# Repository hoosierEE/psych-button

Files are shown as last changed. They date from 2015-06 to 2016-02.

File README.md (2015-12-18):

Psych-Button
============
USB response boxes with real-time accuracy.

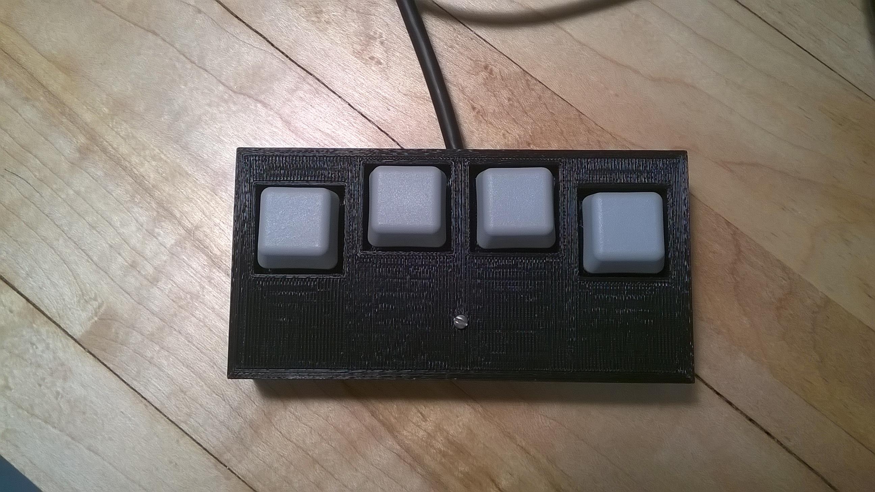
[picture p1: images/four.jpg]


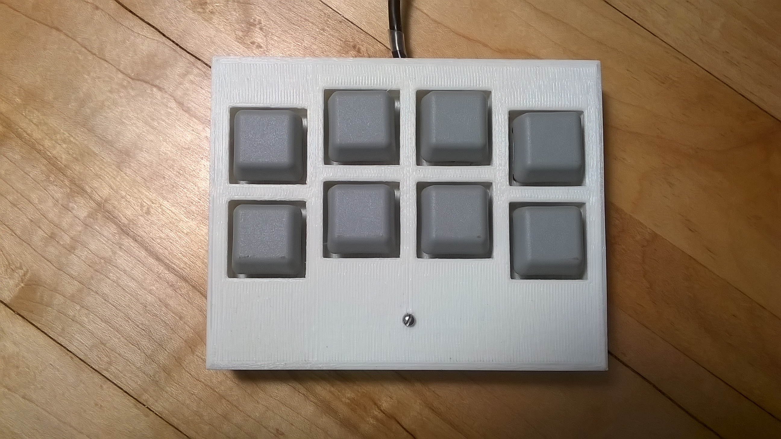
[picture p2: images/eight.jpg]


Often in psychological experiments, researchers wish to record button presses with accurate timing.  Operating system timing resolution may be inadequate, so out-of-band timing channels are required.

This project centers around a USB keyboard-like device that allows a user to measure its latency.

# Keyboard Quick Start
To use as a USB keyboard, plug-and-play.  The default keys are:

* Four-button version (left-to-right)

  * Top row: <kbd>w</kbd> <kbd>x</kbd> <kbd>y</kbd> <kbd>z</kbd>
  * Metal: <kbd>_</kbd>

* Eight-button version (left-to-right)

  * Top row: <kbd>a</kbd> <kbd>b</kbd> <kbd>c</kbd> <kbd>d</kbd>
  * Middle row: <kbd>e</kbd> <kbd>f</kbd> <kbd>g</kbd> <kbd>h</kbd>
  * Metal: <kbd>_</kbd>

> Note: if the home key (the metal pin near the center-bottom of the response box) is held, subsequent key presses will be shifted, e.g. 'a' will become 'A'.

### Timing Measurements
Round-trip delay `d` is calculated as per the [SNTP protocol, section 5](https://tools.ietf.org/html/rfc4330#section-5):

    Timestamp Name          ID   When Generated
    ------------------------------------------------------------
    Originate Timestamp     T1   time request sent by client
    Receive Timestamp       T2   time request received by server
    Transmit Timestamp      T3   time reply sent by server
    Destination Timestamp   T4   time reply received by client

    The roundtrip delay d and system clock offset t are defined as:

    d = (T4 - T1) - (T3 - T2)     t = ((T2 - T1) + (T3 - T4)) / 2.

Timing measurement from `psych-button` uses a modified version of SNTP, where `psych-button` responds to a timing request with a single number that corresponds to T3-T2.  In this scheme, T2 is always 0.  T3 is measured in integer microseconds.  Offset is not used, because `psych-button` doesn't keep a wall clock time.  The only figure we're interested in is the round-trip delay.

This procedure is done at least once, usually before an experiment, but can be done at any point in time except during data collection.

    PC (note system time T1), send character: 'T'
    psych-button: T3
    PC (note time of reply T4, calculate d given T3, T2=0)

### Python pyserial example

    cd examples/
    python pythonExample.py

The results from this test is a list of 100 numbers, corresponding to timing measurements before (t1) sending a `T` and after (t2).  The plot below (generated by [this script](images/stats.ijs), written in [J](http://www.jsoftware.com/)) shows the results of one such test, highlighting the standard deviation (blue), variance (red), arithmetic mean (green) and differences (t2<sub>i</sub> - t1<sub>i</sub>, violet):

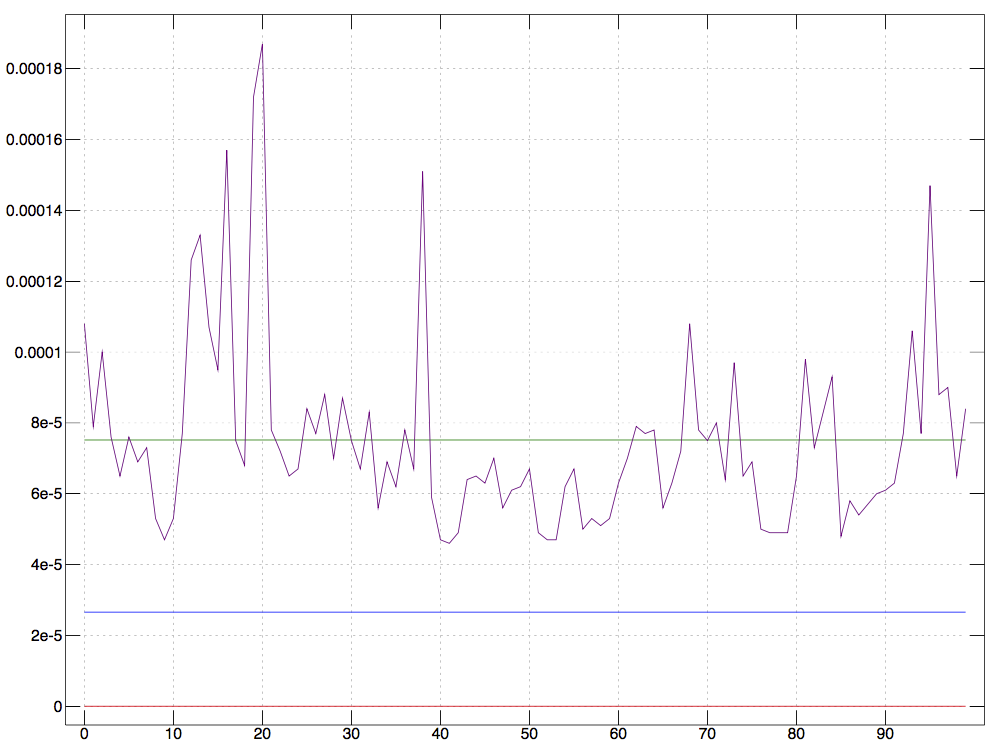
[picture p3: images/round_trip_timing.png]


Usage (Keyboard)
----------------
The Keyboard interface sends a `keydown` event when a button is pressed, or a `keyup` event when it is released.

The Keyboard interface is plug and play.  By default, the 4 (or 8) buttons correspond to <kbd>w</kbd>, <kbd>x</kbd>, <kbd>y</kbd>, and <kbd>z</kbd> keyboard events.  The "home" button prints a `_` (underbar).  Open a text editor and use the response box to "type" letters.

| button | key |
|---|:---:|
| 0 | <kbd>w</kbd> |
| 1 | <kbd>x</kbd> |
| 2 | <kbd>y</kbd> |
| 3 | <kbd>z</kbd> |

> Note: the 8-button box has the default alphabet `abcdefgh`

Usage (Serial)
--------------
Serial mode allows for monitoring the keys pressed, just like Keyboard mode, but in addition provides the following commands:

| Command | Function |
|---|---|
| `l` | list alphabet |
| `L` | modify alphabet |
| `T` | query latency |

> Note: These commands are processed immediately and may interrupt data taking, so only use them when not waiting for data.

When any button changes, the Serial interface responds by printing the state of all the buttons on a single line.

To use the serial interface, open a serial terminal on your computer using a program such as [pyserial](https://github.com/pyserial/pyserial).  Use the following settings:

* 9600 baud
* 8 data bits
* no parity
* 1 stop bit

Pressing and holding the `b0` button (and no others) will result in one line of output:

    1 0 0 0 0

Meanwhile, if you press the `b3` button, while continuing to hold `b0`, the next output will be:

    1 0 0 1 0

Finally, releasing the `b3` button, and then releasing the `b0` button, will produce this output:

    0 0 0 1 0
    0 0 0 0 0

The eight-button box is similar (here showing `b1` pressed, then released):

    0 1 0 0 0 0 0 0 0
    0 0 0 0 0 0 0 0 0

> Note: the "home" button is the last value in the line.

Notes
-----
Source code built with [platformio](http://platformio.org/#!/), a cross-platform command-line based build tool and dependency manager.

Related Reading
---------------
* [example Python serial application](http://eli.thegreenplace.net/2009/08/07/a-live-data-monitor-with-python-pyqt-and-pyserial/)
* [Synchronization Explained](http://www.ni.com/white-paper/11369/en/)
* [NTP](https://en.wikipedia.org/wiki/Network_Time_Protocol#Clock_synchronization_algorithm)
* [PTP](https://en.wikipedia.org/wiki/Precision_Time_Protocol)

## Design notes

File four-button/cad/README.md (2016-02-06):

The "source code" in this folder are CAD files ending in `.skp` which is readable by [Sketchup](http://www.sketchup.com/).

Other files include `.mtl` which are files used by Sketchup to render the "materials" of the part correctly, and `.obj` files which are used by MakerBot desktop software to 3D-print the objects.

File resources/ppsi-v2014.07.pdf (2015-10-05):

# PPSi Manual

July 2014 (ppsi-v2014.07)
Documentation about “PTP Ported to Silicon”

## Alessandro Rubini and Aurelio Colosimo for CERN (be-co-ht)

i

## Table of Contents

Chapter 2: Status, Features, Bugs | 1

## Introduction

PPSi (ptp Ported to Silicon) is an application which, in its basic operation, implements ieee 1588 specification in a way that is portable to several architectures, including OS-less ones. This manual is mainly aimed at developers: people who are working with ptp and/or White Rabbit and need to use the protocol in their own hardware or software environments. Users who simply run PPSi on the host may want to read Chapter 10 [Command Line], page 13 and little else.

## 1 Project Overview

This project originates in the context of White Rabbit, which is shortened to WR in this manual. WR is a multi-lab research project that aims at synchronizing thousands of I/O devices distributed in a network several kilometers wide; its software protocol is an extension of ptp. A WR network is made up of two devices: the WR Switch and the WR Node. White Rabbit is developed at ohwr.org: http://www.ohwr.org/projects/white-rabbit.

The WR switch is an 18-ports Gigabit Ethernet switch that runs wr-ptp as a Linux process, synchronizing each Ethernet link as either a ptp master or a ptp slave (it is a boundary clock). The WR node is an I/O device that includes a soft core that runs wr-ptp in freestanding mode (i.e., without an operating system).

PPSi, as a software package, is designed to be the ptp implementation used in WR, running both standard ptp and wr-ptp, in all possible use cases.

The algorithm and computation routines regarding the basic ieee 1588 are derived from the PTPd project, v.2.1.0 (see AUTHORS for details about copyright); but as of March 2013 very little remains of the original code base. In addition to the basic feature set we inherited from PTPd, we support raw Ethernet frames (ETH_P_1588), according to Annex F of the specification and support for protocol extensions.
We thank Danilo Sabato for fixing the bare architectures (see Section 2.2 [Architectures], page 2).

The home page of the PPSi project and the source repository are:

http://www.ohwr.org/projects/ppsigit://ohwr.org/white-rabbit/ppsi.git

## 2 Status, Features, Bugs

This document tries to summarize the status of the project, but we are working a lot on the package, so information here may be slightly out of date with respect to code.

The software package is designed to be modular: each of architectures, protocols and timing engine can be replaced by providing a proper subdirectory.

## 2.1 Build-time Configuration

After release 2013.11 we added to PPSi the Kconfig configuration engine. Configuration is now performed by running “make menuconfig” or equivalent command.

A number of ready-to use configuration files are distributed in the configs/ directory: to use any of them name it as target of make (for example: “make wrs_defconfig”).

The default configuration is unix defconfig, that builds a Unix daemon running the standard ptp version 2 protocol.

Chapter 2: Status, Features, Bugs | 2

## 2.2 Architectures

When building PPSi, the user can specify which architecture to build for, by selecting it in make menuconfig or equivalent configuration command. When cross-compiling, you need to tell your cross-compiler prefix in the configuration step, or override it at build time by passing CROSS_COMPILE= on the commabnd line.

The package currently supports the following architectures:

unix

This is the default architecture and is the normal hosted environment. The architecture is usually tested over the Linux kernel using the standard GNU libraries. Most of the code relies on standard posix conventions, so this architecture most likely works on bsd and other variants as well. We may change naming accordingly, after identifying the weak (i.e. unportable) points. This architecture supports the standard protocol on both udp and raw Ethernet, also both at the same time thanks to the per-link split of I/O methods. The architecture relies on time-unix, but it supports building with different time engines.

wrs

The White Rabbit switch build of PPSi is designed to be a separate architecture, even if the switch itself is a Linux system running on an ARM processor. The switch is a complex system, with several daemons cooperating through an IPC mechanism: the standard main loop for a standalone Unix daemon doesn’t apply to the WR switch, and modelling it as a separate architecture is the simplest and cleanest approach, in our opinion (even if it leads to some code duplication). The architectures relies on time-wrs.

wrpc

The White Rabbit PTP Core architecture is a port of PPSi to run on our I/O devices. The wrpc is a “core”, i.e. a logic block, that runs in WR-capable I/O cards. Most such cards are developed as open hardware on ohwr.org; examples are the spec (a PCIe carrier for FMC devices) and the svec (a VME carrier, with two FMC slots driver by the same WR core). The wrpc includes a soft-core cpu that runs the wr-ptp daemon. PPSi is designed to be able to be linked from wrpc-sw as its own wr-ptp engine. PPSi in this environment currently supports only raw Ethernet, not udp. The architecture uses time-wrpc.

sim

This is a simulator. It uses special time and network operations to simulate a master and a slave exchanging ptp frames. Arch-specific configuration options are implemented in arch-sim/sim-conf.c. Use of the simulator is briefly descibed in Section 3.2 [Configuring the Simulator], page 6.

bare-i386

This architecture uses system calls towards the Linux kernel but does not rely on standard libraries. The port only supports raw Ethernet frames and is thought to be a validation for our freestanding ports. The process built as bare-i386 runs on conventional x86 Linux hosts and demonstrates that PPSi works properly with no added dependencies on external libraries; freedom from dependencies is mandatory to retain the ability to build and run in freestanding environments like wrpc or microcontrollers.

Chapter 2: Status, Features, Bugs | 3

bare-x86-64
Like bare-i386, this architectures makes direct system calls without relying on external libraries. The host in this case is the a 64-bit PC instead of a 32-bit one. Both bare ports use time-bare for their timing operations.

We plan, over time, to support microcontrollers (a beta version for ARM7 is working, and we are considering Cortex-M) and bare-arm (to be tested on the WR switch).

## 2.3 Protocols

At build time, the user can select the standard protocol (selected by default by most architectures) or an extension. The code base only includes one extension, White Rabbit, which is the default choice when building for one of the WR architectures. Nothing in PPSi prevents our fellow developers to support their own ptp extension using PPSi.

Each extension lives in a subdirectory called proto-ext-name. Source files in that directory may override the implementation for the standard protocol (which lives in proto-standard) to provide their own functionalities. To simplify writing extensions, the proto-standard functions already provide hooks so the extension itself can provide callbacks while still using the basic ptp engine. The set of callbacks is currently based on the needs of WR, but we are willing to accept patches to provide more hooks as needed.
If you plan to write your own protocol extension within PPSi, please refer to how proto-extwhiterabbit is implemented.

## 2.4 Time Functions and Network Operations

PPSi supports custom implementations of time functions, so you can easily port the daemon to your own timing primitives.
The subdirectories named time-sth are used to implement timing functions; timing includes the methods that are part of two data structures: pp time operations and pp network operations. The former structure deals with getting and setting system time, while the latter deals with frame tx and rx. Network operations are concerned with timestamping the actual I/O, and that’s why they are considered part of the “timing” of PPSi.

Each architecture defines its own TIME= choice in the specific Makefile. The user can override the default by either setting the variable on the command line of PPSi, or by setting an environment variable if the architecture supports it. For example, the bare architectures force TIME=bare, while the unix architecture suggests Unix timing code (TIME?=unix). The choice for TIME= is not currently selected using Kconfig, because nobody is expected to diverge from the default choice for the architecture being built.

If you want to support a different timing engine within the Unix build system, you can use “make TIME=xyz” to request building the time-xyz subdirectory. Please note that the Unix time structures are built anyways for CONFIG_ARCH=unix, so you can piggy-back on those functions, either within your own methods or by replacing the ppi->t_ops and ppi->n_ops for the communications links that do not include your own hardware support.

## 2.5 Features

This is a summary of current and planned features for the PPSi package. As said, we are working on it these months, so the following list me be not up to date with software developments by the time you read it.
The following list if features doesn’t consider known bugs, which are listed in the following sections. Please consider such bugs transient mishaps, as we are working on them right now; anyways, it would be unfair to hide them.

Chapter 2: Status, Features, Bugs | 4

Support standard ptp and extensions. Each protocol extension should fall back to standard ptp when it detects that its peers are not able to speak the extended protocol. We don’t plan to support more than one extensions in a single build: it would be just an academic exercise until somebody contributes a new protocol extension to PPSi.

Support both hosted and freestanding environments. This is already supported, though we still lack a microcontroller implementation, and our only freestanding environment is wrpc, running on an LM32 processor.

Support multi-link operation.
The daemon manages several links at the same time, being master slave or autodetect independently on each link. The best master clock algorithm is run globally, but communication and timeouts are managed per-link.

Support both udp and raw Ethernet. We already do that. We plan use the multi-link operation to support both udp and raw Ethernet on the same network interface. Also, we expect to support udp in the WR switch, to allow progressive and seamless migration to WR if you already support ptp in your network with a udp-only implementation.

Support fall-back master links. This is needed for WR, and is being worked on. We need to track more than one master in order to switch over from one to the other within a few milliseconds and with no time glitches.

Support hardware timestamping where available. This is not yet implemented for the generic protocol, but we plan to add at least time-linux-tstamp soon.

Support bsd specifics.
Unfortunately the hosted part of the packages is slightly too much Linux-dependent. We plan to support the bsd variants as well, hoping to get interest and patches from some bsd developer.

Allow architectures to state their capabilities. Currently the command-line arguments are a an all-or-nothing thing. But, for example, bare architectures don’t support udp and other architectures may not support raw Ethernet. We plan to allow architectures to state their capabilities to report proper errors when the user tries to set up unimplemented configurations.

Support run-time enable/disable of diagnostics. We want to allow run-time modification of diagnostics flags with a per-link granularity. Currently we have configuration-based per-link diagnostic flags and global flags that can be changed at run time (for example, arch-wrpc offers that through a shell command). We think this feature is useful when you run more than a pair of interfaces and have problems on some of the links but not all of them.

## 2.6 Bugs

As of 2013-05 the project suffers from these known bugs:
- All frames must be sent according to a pseudo-random distribution; this is mostly in place but mut be audited project-wide.
- We removed peer-delay support. We plan to add it back, and actually move White Rabbit to use peer-delay ptp instead of end-to-end ptp.
- The servo for standard-ptp must be audited. We are doing it now using arch-sim support,
- udp over IPV6 is not yet supported.

Chapter 3: Configuration | 5

## 3 Configuration

PPSi support configuration files and individual configuration items passed on the command line. Such support is currently not available for freestanding architectures (the bare ones and wrpc-sw).
When PPSi starts it parses its own configuration. The command line can include a number of -f <file> and -C <item> options; they are processed in order, so later ones override earlier ones. A configuration “item” can include several directives, using the semicolon as a separator. If no configuration file is specified, the program reads the default one, which is architecture-specific (thus, the default configuration file is processed after all the command line configuration items. The default file name is /etc/ppsi.conf, but arch-wrs tries to load /wr/etc/ppsi.conf first. The source tree of PPSi includes two example configuration files in its own etc/ subdirectory.
Configuration is made of of global options and port-specific options. To configure a port, use port <name> followed by its options. The parser allocates a new ptp state machine for each new port, but allows changing configuration of an existing port. For instance, to enable frame diagnostics for a specific port, you can use:

./ppsi -f /etc/ppsi.conf -C "port eth1; diagnostics 02"
Each configuration item is made up of a keyword and an optional argument. The argument can be either a number or a string. The parser looks up keywords in three tables: a global table, an architecture-specific table and an extension-specific table. Currently, only arch-sim has specific configuration items.
The list of global configuration items is on show in lib/conf.c, as the pp_global_arglines array. Future versions of this manual may document the keywords, if the time allows it. Note: most current command-line options are going to be turned into configuration options. This applies to the priorities, intervals and thresholds, as well as the slave-only flag.

## 3.1 Configuring Faults

Configuration, for arch-unix and arch-wrs, allows to provide some fault injection.
In particular, the program allows dropping frames, in both the TX and RX paths. The configuration values state how many frames are dropped every 1000. Dropping is randomized, but the user can set the seed to ensure a repeatable dropping sequence.
Dropping transmitted frames is performed by reporting success (and the timestamp), while no frame is actually sent. A diagnostic message is generated at frames level 1, but other than than that nothing happens. Actually, arch-wrs needs to actually send a frame in order to get a timestamp back; in this case the program modifies the frame, to use a wrong Ethernet type or a wrong UDP port.
Dropping received frames is performed by actually receiving (and timestamping), but returning a special error code to the caller. Again, PPSi creates a diagnostic message at frames level 1. The following configuration lines are supported:

rx-drop <value>
tx-drop <value>
Drop value frames every 1000 frames received or sent. The randomized sequence is global.

The randomization see can be passed by pre-setting the environment variable PPSI_DROP_SEED to a decimal numeric value. For example:

export PPSI_DROP_SEED=33
before starting the daemon.

Chapter 5: Diagnostics | 6

## 3.2 Configuring the Simulator

To run the PPSi simulator you need to rely on diagnostics and specific configuration items. The configuration items are defined in arch-sim/sim-conf.c and are not individually documented here at this point.
After building with “make sim_defconfig”, you can look at how PPSi behaves in different situation. For example, to see how the servo works with default parameters you can activate servo messages at level 2, and only look at the offset from master:
./ppsi -d 0002 | grep ’Offset from master’
The diagnostic values are specified in the range 0 to 2 and represent, in this order: state machine, time, frames, servo, bmc, extensions. See Section 5.1 [Diagnostic Macros], page 6 for details. The simulator runs by default for one hour of simulated time (in a fraction of a second of running time), and the initial offset from master to slave is 0.9 seconds.

To pass configuration options, you can use the -C command line option. so, for example, to start with 0.1 seconds of offset and 1000 ns of transmission jitter, you can run like this:

./ppsi -d 0002 -C "sim_init_master_time .1; sim_jit_ns 1000"

## 4 PTP Clock Class

The clock class value (clockClass), a field of the “clock quality” structure, can be specified in the configuration file for the architectures that support such a file.
For the White Rabbit node (arch-wrpc) the class is defined according to build-time constants, set forth in constants.h.
When the node is configured as grandmaster (WRPC shell command mode gm), the class is set to 6 (a clock synchronized to a primary reference time source). However, if the internal PLL can not lock in a 60 seconds timeout, the class is set to 52: a clock that will never be a slave, but is not currently connected to a primary time source.
When the node is configured as master, it uses class 187, i.e. a clock that may be a slave of another clock.

## 5 Diagnostics

During development of PPSi, diagnostic support used several techniques, but finally we converged on the one described here, that is here to stay. The idea is that we need to add verbosity per-feature and per-port. This fine-grained control is expected to be important while developing features or while diagnosing problems on new architectures.
The diagnostics configuration keyword can be used both as a global item and as a port-specific configuration value.

## 5.1 Diagnostic Macros

The header file <ppsi/diag-macros.h> introduces the concept of diagnostics flags, which are hosted in both a global variable and pp instance (i.e. one flags-set for each communication link). The macros use the logical OR of both flags, so developers can activate diagnostics on either a single link or globally.
The diagnostic flags are split into topics (called things). For each diagnostic thing the header defines a few bits; so we can have diagnostic levels for each of them, but we suggest only using level 1 and 2 – the rationale is in the header itself.
The things currently defined are:

Chapter 5: Diagnostics | 7
- Finite State Machine: PPSi reports FSM state transitions.
- Time: at level 1 PPSi reports time set operations and timeouts; at level 2 it also reports time get operations.
- Frames: at level 1 PPSi reports any send and receive event; at level 2 it also shows the frame itself (using ptpdump code).
- Servo: report servo operation. At level 2 it also shows the individual timestamps and internal averaging.
- BMC: at level 1 PPSi reports BMC choices, at level 2 it reports addition of new masters as well.
- Extensions: extension-specific information.
- Configuration: at level 1 PPSi reports errors, at level 2 all configuration items being parsed (from either files or command line).

The user is expected to pass diagnostic flags as a string, specifying diagnostic levels for each of the things, where trailing zeroes are optional. So for example “01” specifies a diagnostic level 1 for time, and “102” specifies FSM at level 1 and frames at level 2. The header itself is more detailed about the conventions.
To parse the diagnostic string, PPSi offers pp diag parse. The function is used by both the code that reads the command line and code that parses configuration.
Within PPSi, developers should insert diagnostic messages by means of the pp diag function: pp_diag(ppi, thing, level, ...) The function acts like printf, with the leading arguments ppi, thing (which is one of the names fsm, time, frames, servo, bmc, ext) and level, which should be 1 or 2. For example, the code setting system time includes this diagnostic line:
pp_diag(ppi, time, 1, "%s: %9li.%09li\n", __func__, tp.tv_sec, tp.tv_nsec);
Finally, if you need to shrink the size of your binary file, you can build PPSi with no diagnostic code at all (i.e., the compiler won’t even generate the function calls), you can define PPSI_NO_DIAG in CFLAGS while building. This can be achieved by setting USER_CFLAGS:

make USER_CFLAGS="-DPPSI_NO_DIAG" For more details please refer to the header file, which is throughly commented.

## 5.2 Older Diagnostics

We introduced the diagnostic macros described above at the beginning of March 2013. Earlier code used a less-structured approach, which has later been removed. If you used PP_PRINTF, it’s gone by now.

## 5.3 Printf

The code uses pp printf as a replacement for printf. This implementation comes from previous work by Alessandro, which in turn uses an older Linux implementation. Now pp printf is published separately, as the “Poor Programmer’s Printf” and included here in its own subdirectory. Please check pp printf/README for more details about the size of this implementation and the different implementation choices.
By avoiding calls to the real printf function we allow the PPSi code base to be built for freestanding implementations without ugly #ifdef tricks in the code. Please note that pp printf and printf can coexist: for example the hosted version of PPSi links with the standard library without any problem; in that case pp printf relies on fputs to write to stdout.
If your run-time environment already includes an implementation of pp printf, you can build with CONFIG_NO_PRINTF set. For example:

Chapter 6: Tools | 8

make USER_CFLAGS="-DCONFIG_NO_PRINTF" The resulting ppsi.o will include undefined references to the pp_printf symbol, which must be provided externally. This is how we build for arch-wrpc, which already includes its own implementation if pp printf. In that specific situation we still link the libc provided by the compiler, but we don’t want to lift its own printf which would bring in most of newlib and would overflow our available RAM by a huge amount.

If your freestanding environment provides a printf that you want to use, and which is not called pp printf, you may use the PROVIDE keyword in your linker script. You can find an example in the wrpc-sw package, which maps mprintf to pp printf at link time, in order to accept external code that calls mprintf, which we don’t provide any more.

## 6 Tools

The PPSi package includes some tools, mainly meant to help developers. Most of them live in the tools subdirectory and must be built separately with “make -C tools”.

## 6.1 ptpdump

This is a sniffer for ptp frames. It reports all Ethernet frames and UDP datagrams that talk ptp, from a specific network interface. The output format is line-oriented to help running grep over log files. The number of blank lines between frames depends on how much time elapsed between them; this should help identifying sync/follow-up pairs at a glimpse of the eye.

The program receives one optional argument on the command line, which is the name of the interface where it should listen; by default it uses eth0.

This is, for example, the dump of two UDP frames:

TIMEDELTA: 977 ms
TIME: (1362504223 - 0x51362a1f) 18:23:43.958091 ETH: 0800 (00:22:15:d7:c0:ef -> 01:00:5e:00:01:81) IP: 17 (192.168.16.1 -> 224.0.1.129) len 72
UDP: (319 -> 319) len 52
VERSION: 2 (type 0, len 44, domain 0)
FLAGS: 0x0002 (correction 0x00000000) PORT: 00-22-15-ff-fe-d7-c0-ef-00-01 REST: seq 29, ctrl 0, log-interval 0 MESSAGE: (E) SYNC
MSG-SYNC: 1362504223.957872054
DUMP: payload (size 44)
DUMP: 80 02 00 2c | 00 00 02 00 | 00 00 00 00 | 00 00 00 00
DUMP: 00 00 00 00 | 00 22 15 ff | fe d7 c0 ef | 00 01 00 1d
DUMP: 00 00 00 00 | 51 36 2a 1f | 39 17 f7 b6

TIMEDELTA: 0 ms
TIME: (1362504223 - 0x51362a1f) 18:23:43.958259 ETH: 0800 (00:22:15:d7:c0:ef -> 01:00:5e:00:01:81) IP: 17 (192.168.16.1 -> 224.0.1.129) len 72
UDP: (320 -> 320) len 52
VERSION: 2 (type 8, len 44, domain 0)
FLAGS: 0x0002 (correction 0x00000000) PORT: 00-22-15-ff-fe-d7-c0-ef-00-01 REST: seq 29, ctrl 2, log-interval 0 MESSAGE: (G) FOLLOW_UP
MSG-FOLLOW_UP: 1362504223.957953221
DUMP: payload (size 44)
DUMP: 88 02 00 2c | 00 00 02 00 | 00 00 00 00 | 00 00 00 00
DUMP: 00 00 00 00 | 00 22 15 ff | fe d7 c0 ef | 00 01 00 1d
DUMP: 02 00 00 00 | 51 36 2a 1f | 39 19 34 c5

Chapter 6: Tools | 9

## 6.2 pps-out

The tool outputs a pulse-per-second signal to a parallel port or a serial port. Most likely it only works on an x86 Linux system because of direct access to I/O ports – no such portability problem is expected for serial ports. For this reason it is not built by default in the distributed tools/Makefile
The program receives a single argument on the command line, which is either an hex port number (with or without leading 0x) or an absolute filename:

./tools/pps-out 378
./tools/pps-out /dev/ttyS0 When passed a port number, the program toggles all bits assuming it refers to a parallel port. When passed a pathname, the program assumes it is a serial port and it toggles the DTR and RTS modem control signals (on pins 4 and 7 of the DB9 male connector).

By setting the VERBOSE environment variable you ask the program to report how late it was before and after generating the rising edge:

morgana$ VERBOSE=1 ./tools/pps-out /dev/ttyS0 gettimeofday takes 0.2 usec
udelay takes 4.0 usec
delayed between | 0 and | 2 usecs
delayed between | 0 and | 4 usecs
[...]
pps-out can be used to verify on a scope the level of synchronization of two or more computers, but please note that the user-space software-only approach shows some jitter; on my systems the delay is usually a few microseconds, up to around a dozen (in general, use of the parallel port has less delay and less jitter). In any case this offers a second source to check what NTP or ptp daemons report.

## 6.3 jmptime

The program uses settimeofday to make the local time jump forward or backward by some amount, specified as floating-point seconds:

# date +%H:%M:%S; ./tools/jmptime 1.32; date +%H:%M:%S 12:24:28

Requesting time-jump: 1.320000 seconds
12:24:29

## 6.4 chktime

This program monitors changes in the current time, but comparing the output of clock_gettime(CLOCK_REALTIME) and clock_gettime(CLOCK_MONOTONIC). The delay between successive checks, expressed in milliseconds, can be specified on the command line and defaults to 10ms. The program only reports observed changes that are bigger than 0.5ms, to avoid excessive reporting of false positives that are simply due to process latencies induced by the system workload.
By running this program you can see the effect of tools/jmptime, or the insertion of a leap second (which is why I wrote this program in June 2012).

For example, this is what chktime reports when running “jmptime .002”. The program doesn’t need superuser privileges:

% ./tools/chktime 50
./tools/chktime: looping every 50 millisecs
13-03-12-12:29:41: | 1996 us

Chapter 6: Tools | 10

## 6.5 adjtime

This program works like jmptime, but it requests a slow adjustment of the time. It receives the requested adjustment on the command line, as a floating point number just like jmptime described above. Additionally, it reports what was the ongoing adjustment using adjtime. See the adjtime(2) man page for details.
Adjustments requested by this program cannot be reported by tools/chktime, even when the overall change integrates to more than half a millisecond, because the change in clock speed affects both CLOCK_REALTIME and CLOCK_MONOTONIC.

You can see adjustment in one host by comparing with the time of another host, for example using tools/mtp, described next.

The following example shows how on my host the kernel adjusts the time by 15ms every 30s (i.e. 0.05%):

# ./tools/adjtime .15; sleep 30; ./tools/adjtime 0 Requesting adjustment: 0.150000 seconds

Previous adjustment: 0.000000 seconds
Requesting adjustment: 0.000000 seconds
Previous adjustment: 0.135000 seconds

## 6.6 adjrate

The program reads and optionally changes the clock rate of the host system using the Linuxspecific adjtimex system call (the same being used in the core PPSi program). It is meant to check adjustment and get acquainted with the involved values.
The numerical argument of the system call is parts-per-million scaled by 16 bits. So for example half ppm is passed as 32768.

The following are example uses of the program on an ntp-driven host:

morgana% ./tools/adjrate --help
./tools/adjrate: use "./tools/adjrate [<adj-value> [ppm]]" morgana% ./tools/adjrate
rate: -407582 (-6.219208 ppm)
morgana% ./tools/adjrate -6
./tools/adjrate: adjtimex(rate=-6): -1 (Operation not permitted) morgana% sudo ./tools/adjrate -6 ppm
morgana% sudo ./tools/adjrate
rate: -393216 (-6.000000 ppm)

## 6.7 mtp

The directory tools/mtp includes a few example programs I wrote for an article about time synchronization. MTP means “mini time protocol”; it uses the T1, T2, T3, T4 idea to report the time difference between two hosts. The program comes in two flavors: UDP and raw Ethernet.

To run a listening server on one host, you can run the program in listen mode:

tornado% ./tools/mtp/mtp_udp -l On the other host, you can run the client that reports the time difference it measures, you can pass either an IP address or an host name:

morgana% ./tools/mtp/mtp_udp tornado
0: rtt | 0.000459000 | delta | 0.099351500
You can continuously monitor the difference by running the program in a loop:

Chapter 7: Build Details | 11

morgana% while true; do ./tools/mtp/mtp_udp tornado; sleep 0.1; done The program mtp packet works in the same way by using raw Ethernet frames (AF_PACKET). It needs an interface name as first argument and superuser privileges.

## 6.8 MAKEALL

The MAKEALL script, in the top-level directory of PPSi builds the program for all known configurations, picking them from configs/. Developers are urged to run it before committing each patch, to ensure they are not breaking the program for configurations they are not using – but sometimes I forgot to do that myself and committed trivially-incomplete changes.
It may happen, however, that some developers experience errors or warnings that others didn’t notice, because of differences in compiler version or library versions.
What follows is an older example run, limited to hosted compilation; currently, with the new Kconfig engine introduced after release 2013.11, MAKEALL ignores command-line arguments and always builds all configurations; but I plan to add the command line back.

% ./MAKEALL unix
###### Build for | arch "unix", ext "", printf xint

text | data | bss | dec | hex filename
15801 | 224 | 344 | 16369 | 3ff1 ppsi.o
34370 | 984 | 380 | 35734 | 8b96 ppsi
###### Build for | arch "unix", ext "", all messages

text | data | bss | dec | hex filename
16850 | 224 | 344 | 17418 | 440a ppsi.o
35410 | 984 | 380 | 36774 | 8fa6 ppsi

## 7 Build Details

This is a summary about the build process for PPSi.
The main Makefile creates directory names from $ARCH and $PROTO_EXT, each sub-Makefile then can augment CFLAGS with "-ffreestanding" or whatever it needs. Similarly, CROSS_COMPILE may be set by sub-Makefiles but please let the environment override it (as no custom pathnames should be edited before building and the pristine package can be used).
The basic state machine is in ./fsm.c. It’s a simple file released in the public domain as we’d like the idea to be reused and the code itself is not worth copylefting – even thought the file is not completely independent from PPSi itself.
All the rest of the package is built as libraries. The link order of libraries selects which object files are picked up and which are not. Additionally, "CONFIG_PRINTF_XINT" or one of the other pp printf configurations can be set to override the default. By default PPSi builds the “full” implementation.
This state-machine source refers to a specific state machine by the name pp state table. The table is picked from a library: either from the extension being selected or the proto-standard one. The table includes pointers to functions, and such names will select which other object files are picked up from the libraries.
Individual architectures can add files to the "OBJ-y" make variable, in order to add their own stuff (like the main function or crt0.o for freestanding stuff). Similarly, architectures can add files to the "all" target. The main Makefile only builds ppsi.o, leaving the final link to the chosen architecture, so for example arch-unix adds ppsi to the all target.
Since code and data space is a problem in the freestanding world (for example, the whole ptp may need to fit in 64kB RAM including data and stack), each state in the state machine of

Chapter 9: Coding Style and Conventions | 12

the standard protocol must be implemented as a separate file. This allows an extension not using that particular function to save the overhead of binary size. Clearly an extension may implement several functions in the same file, if they are known to be all used in the final binary or of it uses -ffunction-sections and -fdata-sections).

## 8 Licensing

The code is licensed according to the GNU LGPL, version 2.1 or later. Some files are individually released to the public domain, when we think they are especially simple or generic.

Both the full and the partial printf code is distributed according to the GPL-2, as it comes from the Linux kernel. This means that any code using our diagnostics fall under the GPL requirements; you may compile and use the diagnostic code internally with your own proprietary code but you can’t distribute binaries with diagnostics without the complete source code and associated rights. You may avoid the GPL requirements by using different printf implementations; if so we’d love to have them contributed back in the package.

The same issue about the GPL license applies to the div64 32 function. We need this implementation in our wrpc code base because the default libgcc division is very big, and we are always tight with our in-FPGA memory space.

For binaries without diagnostic code and the size-optimized division, the LGPL applies, as detailed below.

For licensing purposes, any ‘arch-name’ or ‘time-name’ subdirectory "can be reasonably considered independent and separate works in themselves" (quoting the LPGL text).

Code in the directories provided here is all LGPL, and you may add your own drop-in subdirectories. The LGPL requirements for source distribution and associated permissions won’t apply to any such subdirectory that you may add, even if technically such code is not linked as a library.

## 9 Coding Style and Conventions

The coding style is the one inherited from Linux kernel project (see Documentation/CodingStyle in the kernel sources). However, structures, constants and field names defined by ieee 1588 are kept in the suggested "CamelCase" form. Similarly, the typedefs are left, even if they are really a pain to deal with. Most of this stuff is in include/ppsi/ieee1588 types.h file.

The mostly used prefix is pp_, the short prefix for ’Portable ptp’, which is used for every function related to the algorithm itself (but not in the architecture-specific code).

Some prefixes to the ieee naming are added, in order to improve readability:

EN means "enumeration type". For instance, Enumeration Time Source (defined in the spec at table 7, page 57) becomes ENTimeSource.

PPM_ means "ppsi message", and is used for message types.

Msg means "message" and is used for message structures.

PPS_ means "ppsi state" and is used for state machine’s states definition.

DS means "data set", and is used for the standard Data Sets (e.g. DSCurrent is the "Current Data Set"). The concept of data sets is defined in the specification at chapter 8, page 63.

Chapter 10: Command Line | | 13

## 10 Command Line

The hosted build, as well as the two bare ones, include command line support. The command:

./ppsi --help
will print help about command line options (we also support the question-mark like the original ptp, but it’s a bad choice because it is a shell wildcard that should be escaped). Actually, all multi-char options will print the help at this point in time, because we only support since-char options; we don’t want to rely on getopt which is not available for all architectures, nor we want to implement complex parsing.
Note: most current command-line options are going to be turned into configuration options. This applies to the priorities, intervals and thresholds, as well as the slave-only flag.
For standard operation, simply run ./ppsi with no options. It will work like the PTPd executable, with the automatic choice of master/slave defined in ieee specification (announce/timeout mechanism).

What follows is a list of the most important command line options. For a list of the other ones please see the help message.

-f <file>
Read configuration file. | The program can read several configuration files. | If
no -f is passed, it tries to read a configuration file from the standard places: /wr/etc/ppsi.conf if White Rabbit, and /etc/ppsi.conf.

-C <config-item>
Pass a single configuration item, or several of them using the semicolon as separator. See Chapter 3 [Configuration], page 5 for details.

-d
Diagnostics. This options receives the string of diagnostic levels for fsm, time, frames, servo, bmc, extension (in that order). See Section 5.1 [Diagnostic Macros], page 6 for details.

-b <ifname>
Specify which interface to use, for Ethernet mode (default: architecture-dependent, but eth0 for Linux builds). This option can only be used in single-port operation.

-e
Run in Ethernet mode (by default PPSi uses UDP if the architecture supports it).

-g
Run as slave only.

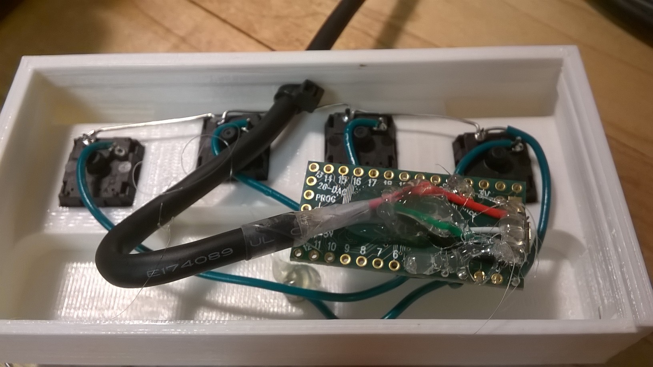
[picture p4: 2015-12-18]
images/interior.jpg

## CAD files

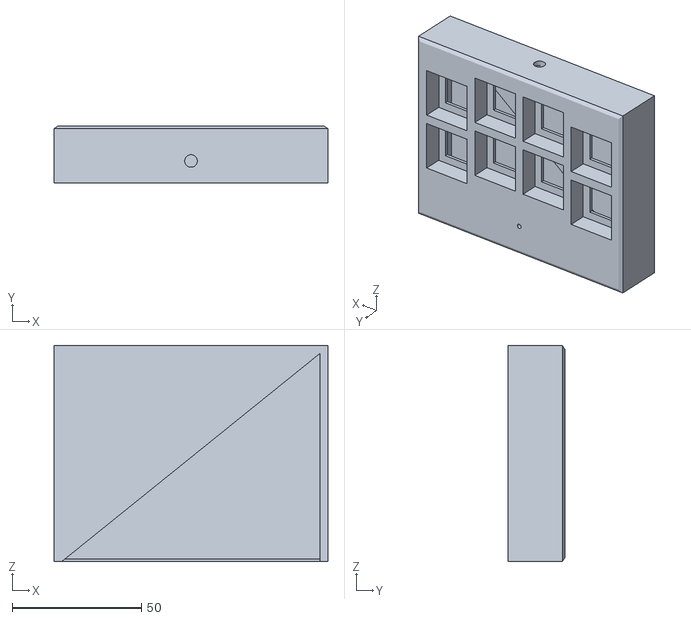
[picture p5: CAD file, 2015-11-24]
eight-button/cad/eight.obj
106.0 x 22.0 x 83.6

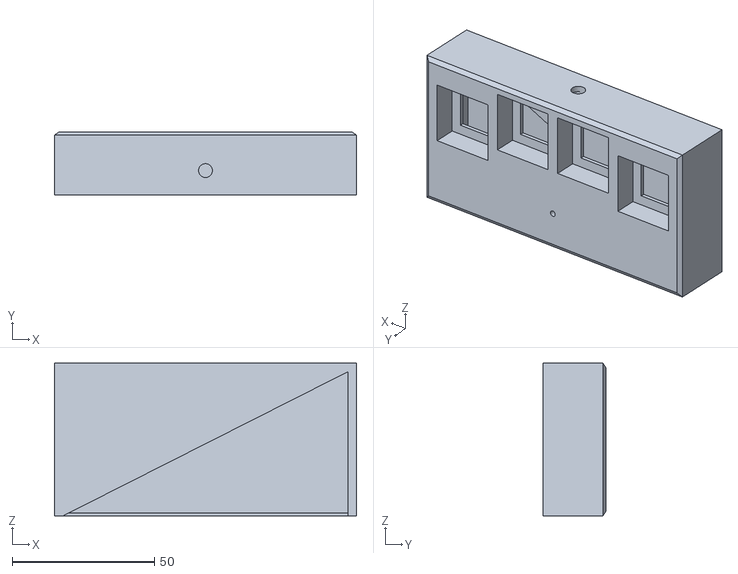
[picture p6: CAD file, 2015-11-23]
four-button/cad/four.obj
106.0 x 22.0 x 53.6

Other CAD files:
eight-button/cad/eight.skp
four-button/cad/four.skp

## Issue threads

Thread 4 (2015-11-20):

quantities

hoosierEE, 2015-11-20:
six smalls

- [x] four-button box
- [x] four-button box
- [x] four-button box
- [x] four-button box
- [x] four-button box
- [x] four-button box
- [x] four-button box
- [x] four-button box

two larges

- [x] eight-button box
- [x] eight-button box

hoosierEE, 2015-11-25:
small boxes printed.

hoosierEE, 2015-12-02:
Only soldering left to do.

hoosierEE, 2015-12-07:
Done!

Closed 2015-12-07.

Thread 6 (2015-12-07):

Holding down home button causes ALL CAPS

hoosierEE, 2015-12-07:
This was perplexing for a while.  At one point I was convinced there was a bug in the Arduino keyboard library.  Now I realize my mental model of the keyboard was incomplete.

Since the home button is represented by <kbd>_</kbd>, which can only appear on a Qwerty-style layout by holding the <kbd>Shift</kbd>, it is logical that holding the home button causes the other keys to become shifted.

An interesting side-effect of this is that, even though non-alphanumeric characters are prevented from being stored in the device's "alphabet", it's possible to cause them to be "typed" by holding the home button.

E.g. if one overrides the default alphabet and sets it to `1234`, then holding the home button shift these to be the characters `!@#$`.  Hopefully this doesn't cause too much swearing.

Closed 2015-12-07.

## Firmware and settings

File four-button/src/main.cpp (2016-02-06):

// Response button firmware for TeensyLC, built with PlatformIO.
//
// Implements a modified SNTP timing protocol,
// where 'server' is a PC and 'client' is this device:
// 1. Server sends "initiate timing procedure" request to client
// 2. Client sets an internal stopwatch timer to 0 (T1), and replies with
//    the number of microseconds that elapsed since it received the message (T2).
//    Note that this is the same value as (T2-T1).
// 3. Server notes when it receives reply (T3)
// 4. Server repeats steps 1-3 often enough to be statistically meaningful

#include <SimpleSwitch.h> // debounce a pin
#include <CapSwitch.h> // capacitive sensor as-a-switch

// perform loop body n times, with capture of loop index i
#define DO(n) for(int i=0,_n=(n); i<_n;++i)

// TIMING
const uint16_t LOOP_TIME{10000}; // in microseconds
elapsedMicros outputTimer; // data rate

// MODEL
const uint8_t NUM_BUTTONS{4};
char l[]{"wxyz"}; // letter defaults
char h[]{"_"}; // home button key '_'
struct KeyState { bool keys[NUM_BUTTONS],ch,hb; } ks; // { keys[], changed, home button }

// HARDWARE CONNECTIONS
SimpleSwitch buttons[NUM_BUTTONS]{
    SimpleSwitch(2),SimpleSwitch(3),SimpleSwitch(4),SimpleSwitch(5) }; // mech. switches
CapSwitch cap(23); // capacitive 'switch' at this pin

bool alnum(char c) { return ((c>='0'&&c<='9')||(c>='A'&&c<='Z')||(c>='a'&&c<='z')); } // true for [09AZaz]
void ub(void) { DO(NUM_BUTTONS){buttons[i].update();} } // update buttons with pin readings
void ut(void) { cap.update(); } // update touch-sensitive "button"
void cl(void) // change letters used by Keyboard
{
    // Note: Power-cycling restores default (wxyz).
    char nl[NUM_BUTTONS]; // new letters
    Serial.readBytes(nl,NUM_BUTTONS+1); // utilizes Serial.setTimeout() default (1000ms)
    DO(NUM_BUTTONS){ l[i] = alnum(nl[i]) ? nl[i] : l[i]; }
    Serial.print("replaced letters with ");
    Serial.println(l);
}

void sr(void)  // read the serial port
{
    // Consume and process at most 1 command from the Serial buffer.
    uint32_t t2{micros()};
    if (Serial.available()) {
        switch (Serial.read()) {
        case 'T': Serial.println(micros() - t2); break; // Time: T3 - T2
        case 'L': cl(); break; // L (change letters)
        case 'l': Serial.println(l); break; // l (list letters)
        default: break;
        }
    }
}

KeyState upks(KeyState k) // update key states
{
    // k.ch = false; // assume no change
    if (cap.pressed()) { k.ch = true; k.hb = true; }
    if (cap.released()) { k.ch = true; k.hb = false; }
    DO(NUM_BUTTONS) {
        if (buttons[i].pressed()) { k.ch = true; k.keys[i] = true; }
        if (buttons[i].released()) { k.ch = true; k.keys[i] = false; }
    }
    return k;
}

void rk(const KeyState &kn, const KeyState &ko) // render keyboard
{
    // 'press' if old was low and new is high
    // 'release' if old was high and new is low
    DO(NUM_BUTTONS) {
        if (kn.keys[i] && !ko.keys[i]) Keyboard.press(l[i]);
        if (!kn.keys[i] && ko.keys[i]) Keyboard.release(l[i]);
    }
    if (kn.hb && !ko.hb) Keyboard.press(h[0]);
    if (!kn.hb && ko.hb) Keyboard.release(h[0]);
    // It's possible this could be expressed more simply as:
    // kn.keys[i] ? Keyboard.press(l[i]) : Keyboard.release(l[i])
    // But it strikes me that a real-world key must be released before
    // it can be pressed again.  Maybe OOP is getting to me...
}

void rs(const KeyState &k) // render (print) serial
{
    DO(NUM_BUTTONS) {
        Serial.print(k.keys[i]); // 0 or 1
        Serial.print(" ");
    }
    Serial.println(k.hb); // 0 or 1
}

// PROGRAM
void setup() {
    Serial.begin(9600);
    Keyboard.begin();
}

void loop() {
    // Update "inputs" at maximum rate:
    // buttons, touch, Serial
    ub(); ut(); sr();

    // Update state and render output at a controlled rate.
    if (outputTimer >= LOOP_TIME) {
        outputTimer -= LOOP_TIME;
        // UPDATE
        KeyState oldks = ks; // save current state
        ks = upks(ks); // get new state
        // RENDER
        if (ks.ch) {
            ks.ch = false;
            rs(ks);
            rk(ks,oldks);
        }
    }
    // Alternatively, UPDATE and RENDER could be done at different rates:
    // // UPDATE
    // if (stateTimer >= STATE_TIME) {
    //     stateTimer -= STATE_TIME;
    //     upks(ks); // Update at one rate...
    // }
    // // RENDER
    // if (renderTimer >= RENDER_TIME) {
    //     renderTimer -= RENDER_TIME;
    //     rs(ks); // ...output at other rate.
    // }
}

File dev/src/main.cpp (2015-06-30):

//
// main.cpp
//
// 4-button response box with USB-Serial timestamps
// For accurate subject timing, initialize with "start" command (using USB Serial)
//

#include "../lib/SimpleSwitch/SimpleSwitch.h"

// HARDWARE
const uint8_t NUM_SWITCHES{4};
SimpleSwitch s0(0);
SimpleSwitch s1(1);
SimpleSwitch s2(2);
SimpleSwitch s3(3);

// MODELS
uint32_t t0;
SimpleSwitch switches[NUM_SWITCHES]{s0,s1,s2,s3};
const char letters[NUM_SWITCHES]{'a','b','c','d'}; // friendly names for buttons
struct KeyState {
    bool keys[NUM_SWITCHES];
    bool prev[NUM_SWITCHES];
    bool changed;
};
struct KeyState ks;

void resetTimer(void)
{
    // TODO this thing
    if (Serial.available()) {
        char inbyte = Serial.read();
        if (inbyte == '0') {
            t0 = 0;
        }
    }
}

void serialize(uint32_t now, struct KeyState *state)
{
    // Send all the buttons (in hex) and a timestamp (in decimal)
    char result{0};
    for (uint8_t i = 0; i < NUM_SWITCHES; ++i) {
        result |= state->keys[i] << i;
    }
    Serial.print(result, HEX); // '0' through 'F'
    Serial.print(" "); // easier for human to read
    Serial.println(now, HEX); // hex is about 12% faster on average
}

// RENDER
void setup() {
    Serial.begin(115200);
    Keyboard.begin();
}

void loop() {
    // UPDATE
    uint32_t now = micros();
    for (uint8_t i = 0; i < NUM_SWITCHES; ++i) {
        switches[i].update(now);
        ks.keys[i] = switches[i].pressed();
        if (ks.prev[i] != ks.keys[i]) {
            Keyboard.write(letters[i]); // do this the instant they arrive
            ks.changed = true;
        }
    }

    // if there were any changes, send an update
    if (ks.changed) {
        serialize(now, &ks); // send these in a batch
        for (uint8_t i = 0; i < NUM_SWITCHES; ++i) {
            ks.prev[i] = ks.keys[i]; // make previous same as current
        }
        ks.changed = false; // reset so we don't send the same update twice
    }
}

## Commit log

2015-06-23 add beginnings of device
2015-06-24 test with teensy31 success
2015-06-27 remove device folder
2015-06-30 stub out timer
2015-10-07 add note about which buttons are pressed to make it explicit
2015-10-08 works pretty good, just needs enclosure
2015-11-12 split into 4 and 8 button devices
2015-11-17 begin to add home button functionality
2015-11-17 update with print-as-binary-array
2015-11-18 replace some calls to Serial.print with snprintf
    [main.cpp]
2015-11-20 some test prints
    [four.skp, fourbuttonbox.skp, singlebutton.skp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]
2015-11-20 some enclosure prototypes
    [four.obj, four.skp, fourbuttonbox.skp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]
2015-11-20 remove 8-button for now
2015-11-20 first stab at capsense library, some errors
    [main.cpp]
2015-11-23 latest enclosure print successful
    [four.obj, four.skp]
2015-11-24 ugly hacks save the day again
    [eight.skp]
2015-11-24 eight button box ready to print
    [eight.obj, eight.skp]
2015-11-25 eight button boxes printing
2015-11-25 copy eight-button source
2015-11-25 modify for 8-button box
2015-11-25 remove debugging lines in four-button main
2015-11-30 keep track of state in CapSwitch instead of main loop
2015-12-01 cleanup and some docs
    [singlebutton.obj, singlebutton.skp, singlebuttontest.obj]
2015-12-02 first 4-button boxed and tested -- kind of flaky when subject is not grounded
2015-12-07 update 8-button code to be very similar to 4-button code
2015-12-07 fix 8-button copy-paste

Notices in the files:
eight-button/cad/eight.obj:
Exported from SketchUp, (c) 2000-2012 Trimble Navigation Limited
